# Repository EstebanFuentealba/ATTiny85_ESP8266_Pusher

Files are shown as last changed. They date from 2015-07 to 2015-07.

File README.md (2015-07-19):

# ATTiny85_ESP8266_Pusher
ATTiny85 + ESP8266 + Pusher.com WebSocket Client

Materiales
===================
- ATTiny85
- 2 Led
- Protoboard
- ESP8266
- Arduino UNO
- USBTinyISP (OPCIONAL Para subir código al ATTiny85)
- Cuenta en Pusher.com
- Cables

Instrucciones
===================
## Crear Cuenta en Pusher.com
Pusher es un servicio que provee de servidores websocket para utilizarlo como uno quiera. Esto funciona con tres actores:
- servicio (pusher)
- servidor (envía eventos)
- cliente (se conecta al servicio escucha y recibe eventos)

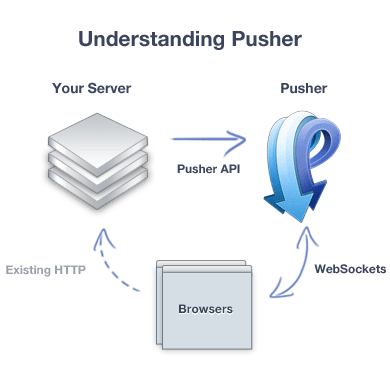
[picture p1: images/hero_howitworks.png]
cómo funciona


De la imagen anterior debemos entender que ATTiny85 funcionará como cliente reemplazando a *Browsers*

Conociendo eso entramos a [https://pusher.com/signup](https://pusher.com/signup) ingresan su email - contraseña o loguearse con alguna cuenta de github o google y confirmar cuenta. Después de eso ya podemos crear apps. Luego de eso los redirecciona a un dashboard y solo deben presionar el botón:

new app

se abre un modal y le damos un nombre y checkeamos *Enable client event* y presionamos *Create App*

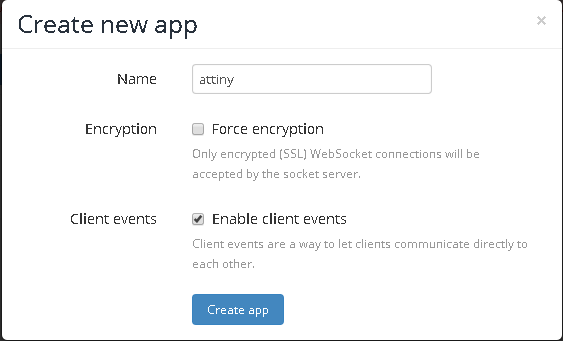
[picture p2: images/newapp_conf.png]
configure new app


ya tenemos una app y podemos comenzar a utilizar el servicio. Nos entrega unos ejemplos de Cliente servidor, pero a nosotros solo nos importará la APP KEY por ejemplo
```
key = '856c493d6d461226XXX'
```

## Actualizar firmware del ESP8266
Lo primero es actualizar el firmware, lo actualizaremos a la versión [AI-v0.9.5.0 AT Firmware.bin](https://github.com/EstebanFuentealba/ATTiny85_ESP8266_Pusher/raw/master/firmware%20esp8266/AI-v0.9.5.0%20AT%20Firmware.bin). Después de probar muchos firmwares es el unico que me funcionó para el ATTiny85 configurado a 4800 bauds.
Primero se sube un sketch vacio al Arduino UNO

```arduino
void setup() {
  // put your setup code here, to run once:
}
void loop() {
  // put your main code here, to run repeatedly:
}
```

Después necesitamos conectar el ESP8266 al Arduino UNO como se ve en el siguiente diagrama

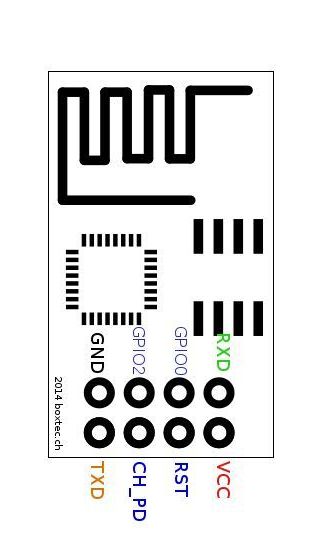
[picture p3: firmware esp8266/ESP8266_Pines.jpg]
ESP8266

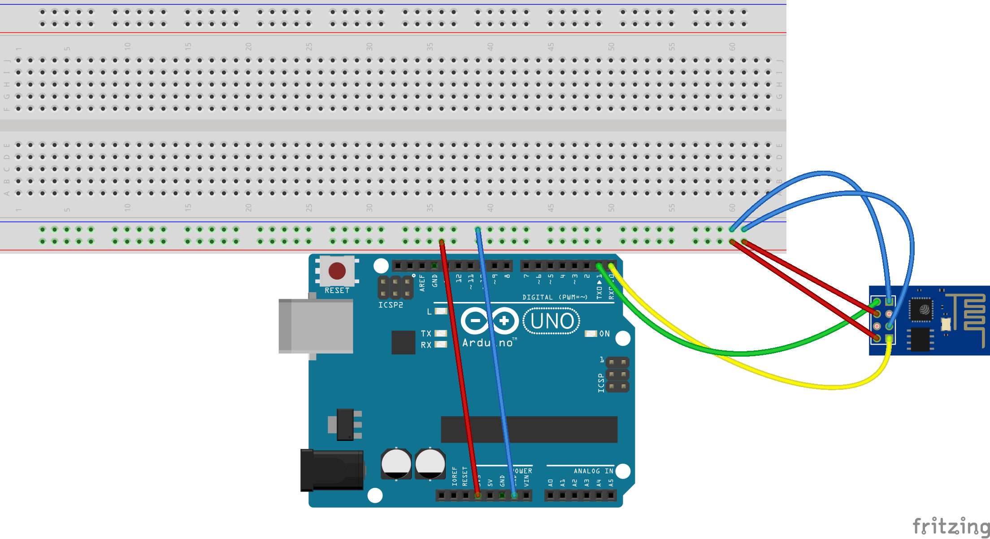
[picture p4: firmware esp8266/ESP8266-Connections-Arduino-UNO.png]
Conexión


Después de conectar utilizaremos el programa [esp8266_flasher.exe](https://github.com/EstebanFuentealba/ATTiny85_ESP8266_Pusher/raw/master/firmware%20esp8266/esp8266_flasher.exe) Para windows o [esptool.py](https://github.com/themadinventor/esptool) para otros sistemas operativos.

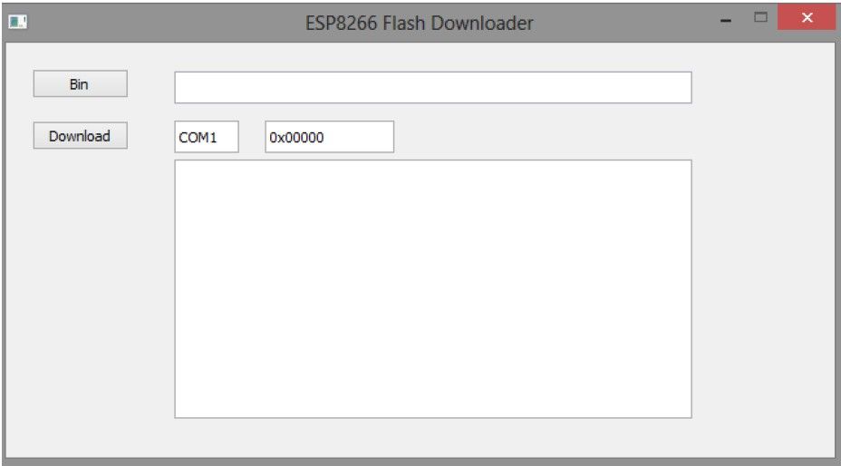
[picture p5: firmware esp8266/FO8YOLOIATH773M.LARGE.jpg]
Programa esp8266_flasher


Se debe seleccionar el archivo presionando el botón "Bin", escribir el puerto donde está conectado el Arduino UNO (COM1) y presionar el botón "Download" , y comenzará a escribirse el firmware en el 8266 imprimiendo algo como lo siguiente

```
connecting ....
Erasing flash...
Writing at 0x00000000... (0 %)
Writing at 0x00000400... (0 %)
Writing at 0x00000800... (0 %)
Writing at 0x0007e800... (99 %)
Writing at 0x0007ec00... (99 %)
Leaving... Failed to leave Flash mode
```

Al terminar de actualizar el firmware deben desconectar del 8266 el pin GPIO0 

## Configurar ESP8266
Despues de tener el nuevo firmware vamos a cambiar un parametro del modulo wifi, debemos dejar el baudaje de comunicación a 4800, por defecto viene con 9600. Para ello nuevamente usaremos Arduino UNO, necesitamos subir el siguiente sketch:

```arduino
#include <SoftwareSerial.h>
SoftwareSerial BT1(3, 2); // RX | TX
void setup() {  
	Serial.begin(9600);
    BT1.begin(9600);
}

void loop() {
	String B= "." ;
	if (BT1.available()) { 
		char c = BT1.read() ;
		Serial.print(c);
	}
	if (Serial.available()){
		char c = Serial.read();
		BT1.print(c);
	}
}
```

y conectaremos el modulo ESP8266 de la siguiente forma:

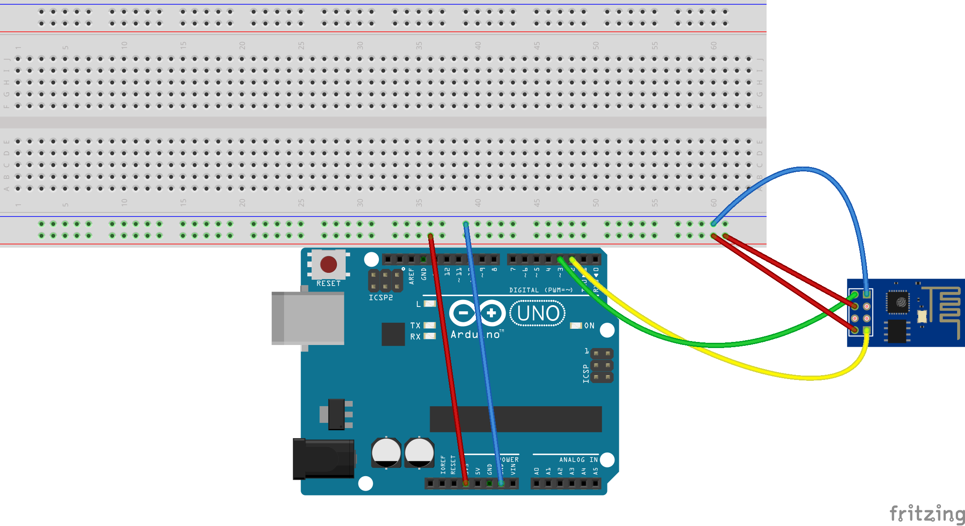
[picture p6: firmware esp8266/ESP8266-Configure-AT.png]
Configurando con comandos AT


Ahora en el programa Arduino vamos a *Herramientas* -> *Monitor Serie* , Seleccionar *Ambos NL & CR* y *9600 baudio*

Configurando Monitor Serie

y podremos ver algo como lo siguiente 

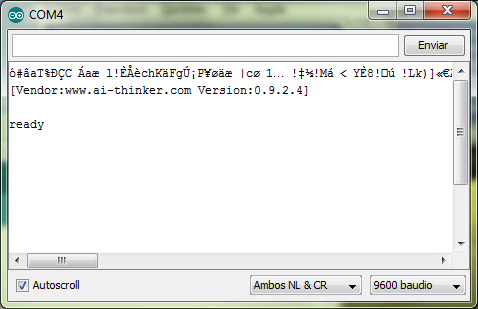
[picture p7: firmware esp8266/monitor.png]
Monitor Serie


Ahora ya podemos comenzar a escribir comandos **AT**, lo primero que podemos escribir es el Comando **AT** que debería responder **OK** 

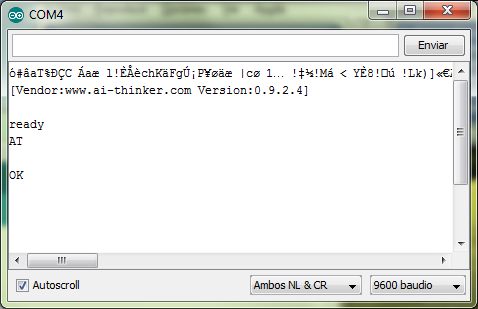
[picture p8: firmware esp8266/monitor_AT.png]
AT


para configurar a 4800 bauds debemos escribir **AT+CIOBAUD=4800** que debería responder **OK** aunque ya no se nos verá el texto porque ahora ya no funciona a 9600 bauds. Para volver a ver texto deben subir nuevamente el sketch anterior pero pasando 4800 al método begin
```arduino
BT1.begin(4800);
```
Ahora ya hemos terminado con la configuración del modulo wifi, aunque si quieren investigar mas [acá dejo un pdf](https://github.com/EstebanFuentealba/ATTiny85_ESP8266_Pusher/raw/master/firmware%20esp8266/ESP8266%20AT%20Command%20Set.pdf) con todos los comandos disponibles que usaremos en los siguientes pasos.

## Subir código al ATTiny85
Para subir el código al integrado Se puede usar Arduino UNO o un ISP yo utilizaré USBTinyISP donde debemos conectar el Attiny85 al ISP de la siguiente forma:

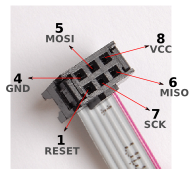
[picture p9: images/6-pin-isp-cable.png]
USBTinyISP
 ATTiny85

Ya conectado debemos agregar ATTiny a las placas del programa Arduino, yo estoy usando la version 1.6.5 que es sencillo, sólo deben ir a *Archivo* -> *Preferencias* donde encontraremos el siguiente campo

Agregar placa

Ahí agregamos éste link que contiene la configuracion del package que contiene las placas ATTiny
```
https://raw.githubusercontent.com/damellis/attiny/ide-1.6.x-boards-manager/package_damellis_attiny_index.json
```
click en OK para guardar la configuración. Ir a *Herramientas* -> *Placa* -> *Boards Manager...* buscar ATtiny y presionar el botón *Install*

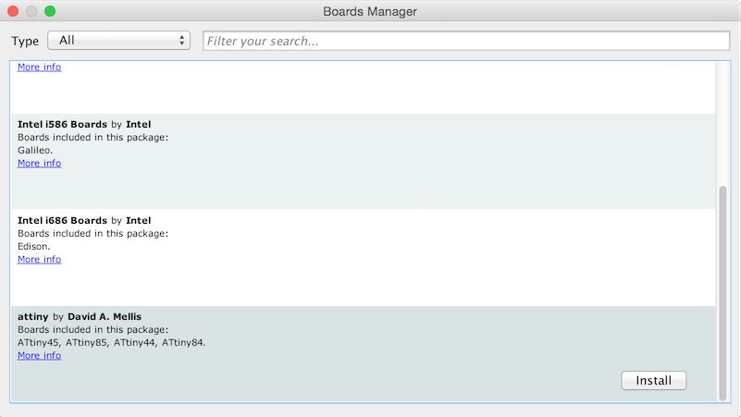
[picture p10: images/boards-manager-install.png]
Install board ATTiny


Ahora ya puedes utilizar ATTiny en Arduino. Ahora configuraremos Arduino Anda a *Herramientas* 
- **Placa** y selecciona *ATtiny*
- **Procesador** ATTiny85
- **Clock** 8 MHz (internal)
- **Programador** USBtinyISP

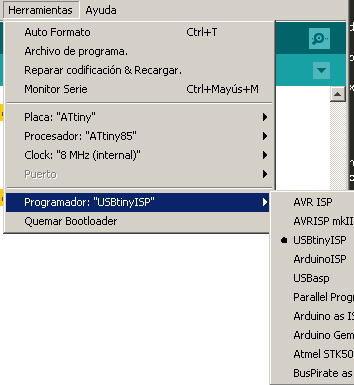
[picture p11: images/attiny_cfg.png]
board ATTiny


Importante es Presionar **Quemar Bootloader**, cuando no hice eso el programa andaba lento

Ahora solo deben configurar [ATTiny85WebSocketClient.ino](https://github.com/EstebanFuentealba/ATTiny85_ESP8266_Pusher/blob/master/attiny85/ATTiny85WebSocketClient.ino) agregando la información de su red wifi y la Key de pusher que obtuvimos en el Paso 1

```arduino
#define SSID        "WifiAP"
#define PASS        "password"
#define PUSHER_KEY  "xxxxxxxxxxxxxxx"
```
El codigo se conecta como Cliente a Pusher esperando eventos en el channel **test_channel**, los eventos que definí son los siguientes:

- **ledAOn** 
- **ledAOff**
- **ledBOn**
- **ledBOff**

esos eventos prenderán o apagarán 2 leds. A continuación dejo el diagrama de como deben ir conectadas las leds y el módulo ESP8266 al ATTiny85

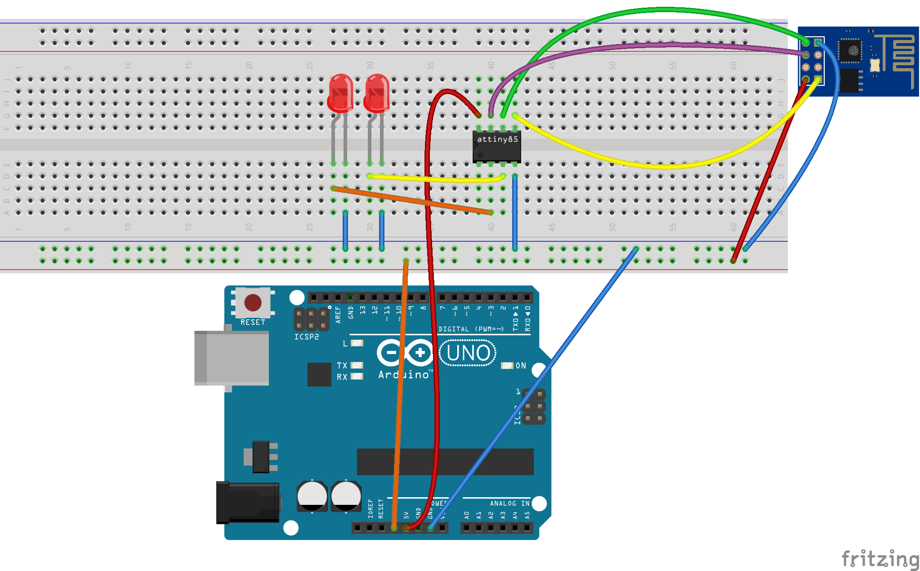
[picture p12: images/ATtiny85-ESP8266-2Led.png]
cableado


Ahora solo debemos subir el código al ATTint85 y esperar que conecte.

## Testeando programa
Aqui dejo un video con el programa y la configuración corriendo

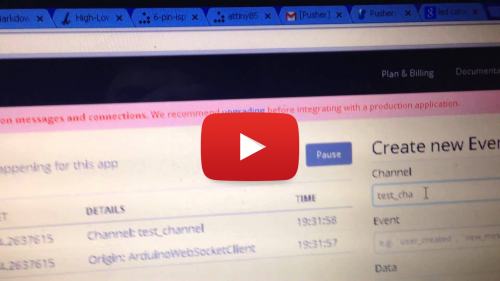
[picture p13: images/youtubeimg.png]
Video (http://youtu.be/ycAC6Tfkjng)


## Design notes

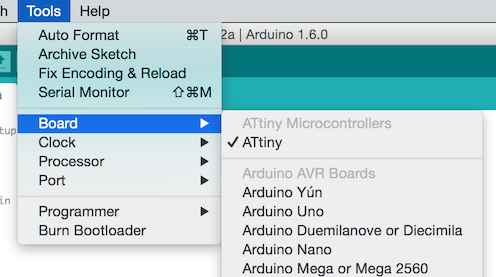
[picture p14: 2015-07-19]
images/ATtiny-Arduino-1.6.png

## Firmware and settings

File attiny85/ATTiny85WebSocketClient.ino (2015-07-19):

#include <SoftwareSerial.h>
/*
*   efuentealba@json.cl
*/
//CONFIGURE
#define SSID        "WifiAP"
#define PASS        "password"
#define PUSHER_KEY  "xxxxxxxxxxxxxxx"


#define SOFT_RX_PIN     1
#define SOFT_TX_PIN     0
#define ESP_ENABLE_PIN  2
#define LED_A 4
#define LED_B 3
#define TIMEOUT     5000
#define CONTINUE    false
#define HALT        true

char str_buffer[64];

const char STR_OK[] PROGMEM         = "OK";
const char WS_OK[] PROGMEM          = "HTTP/1.1 101";
const char WS_PING[] PROGMEM        = "pusher:ping";
const char STR_READY[] PROGMEM      = "ready";
const char STR_SENDMODE[] PROGMEM   = ">";
const char STR_APNAME[] PROGMEM     = "+CWJAP:\"";
const char SUBSCRIBE_JSON[] PROGMEM = "{\"event\":\"pusher:subscribe\",\"data\":{\"channel\":\"test_channel\"}}";
const char PONG_JSON[] PROGMEM      = "{\"event\":\"pusher:pong\",\"data\":{}}";
const char ping[] PROGMEM           = "ping";

/*
*   EVENTOS PUSHER.COM
*/
const char ledAOn[] PROGMEM         = "ledAOn";
const char ledAOff[] PROGMEM        = "ledAOff";
const char ledBOn[] PROGMEM         = "ledBOn";
const char ledBOff[] PROGMEM        = "ledBOff";

bool connected = false;


byte ledAonC   = 0;
byte ledAoffC  = 0;
byte ledBonC   = 0;
byte ledBoffC  = 0;
byte pingC     = 0;


SoftwareSerial SoftSerial(SOFT_RX_PIN, SOFT_TX_PIN); // RX, TX

void setup() {
  pinMode(SOFT_TX_PIN, OUTPUT);
  pinMode(LED_A, OUTPUT);
  pinMode(ESP_ENABLE_PIN, OUTPUT);
  pinMode(LED_B, OUTPUT);
  digitalWrite(SOFT_TX_PIN, LOW);
  digitalWrite(LED_A, LOW);
  digitalWrite(LED_B, LOW);
  digitalWrite(ESP_ENABLE_PIN, LOW);
  SoftSerial.begin(4800);
  //SoftSerial.setTimeout(TIMEOUT);
  delay(300);
  digitalWrite(ESP_ENABLE_PIN, HIGH);
  SoftSerial.println(F("AT+RST"));
  SoftSerial.flush();
  if (!waitForString(getString(STR_READY), 5, 2000)) {
    return;
  }
  digitalWrite(LED_A, HIGH);
  delay(500);
  digitalWrite(LED_A, LOW);
  SoftSerial.println(F("ATE0"));
  SoftSerial.flush();
  if (waitForString(getString(STR_OK), 2, 2000)) {
    digitalWrite(LED_A, HIGH);
    delay(500);
    digitalWrite(LED_A, LOW);
    boolean connection_established = false;
    for (int i = 0; i < 5; i++) {
      if (connectWiFi()) {
        connection_established = true;
        break;
      }
    }
    if (!connection_established) {
      return;
    }
    SoftSerial.println(F("AT+CIPMODE=1"));
    SoftSerial.flush();
    if (!waitForString(getString(STR_OK), 2, 1000)) {
      return;
    }
    SoftSerial.println(F("AT+CIPMUX=0"));
    SoftSerial.flush();
    if (!waitForString(getString(STR_OK), 2, 1000)) {
      return;
    }
  } else {
    //digitalWrite(LED_B, HIGH);
  }
}

void wssend(char *data) {
  SoftSerial.print((char)0);
  SoftSerial.print(data);
  SoftSerial.print((char)255);
  SoftSerial.flush();
}
void loop() {
  if (!connected) {
    SoftSerial.println("AT+CIPSTART=\"TCP\",\"ws.pusherapp.com\",80");
    SoftSerial.flush();
    if (!waitForString(getString(STR_OK), 2, 1000)) {
      return;
    }

    SoftSerial.println(F("AT+CIPSEND"));
    SoftSerial.flush();
    if (waitForString(getString(STR_SENDMODE), 1, 1000)) {

      SoftSerial.print("GET /app/");
      SoftSerial.print(PUSHER_KEY);
      SoftSerial.print("?client=js&version=2.2&protocol=5");
      SoftSerial.print("HTTP/1.1\r\n");
      SoftSerial.print("Upgrade: WebSocket\r\n");
      SoftSerial.print("Connection: Upgrade\r\n");
      SoftSerial.print("Host: ws.pusherapp.com\r\n");
      SoftSerial.print("Origin: ArduinoWebSocketClient\r\n");
      SoftSerial.print("\r\n");
      SoftSerial.flush();
      if (waitForString(getString(WS_OK), 2, 1000)) {

        wssend(getString(SUBSCRIBE_JSON));
        connected = true;

      } else {
        //Serial.println("ERROR http");
      }

    } else {
      SoftSerial.println(F("AT+CIPCLOSE"));
      SoftSerial.flush();
    }
  }

  if (connected) {
    if (SoftSerial.available()) {
      char ch = SoftSerial.read();
      if (ch == getString(ledAOff)[ledAoffC]) {
        if (++ledAoffC == 7) {
          digitalWrite(LED_A, LOW);
        }
      } else {
        ledAoffC = 0;
      }
      if (ch == getString(ledAOn)[ledAonC]) {
        if (++ledAonC == 6) {
          digitalWrite(LED_A, HIGH);
        }
      } else {
        ledAonC = 0;
      }
      if (ch == getString(ledBOff)[ledBoffC]) {
        if (++ledBoffC == 7) {
          digitalWrite(LED_B, LOW);
        }
      } else {
        ledBoffC = 0;
      }
      if (ch == getString(ledBOn)[ledBonC]) {
        if (++ledBonC == 6) {
          digitalWrite(LED_B, HIGH);
        }
      } else {
        ledBonC = 0;
      }
      if (ch == getString(ping)[pingC]) {
        if (++pingC == 4) {
          wssend(getString(PONG_JSON));
        }
      } else {
        pingC = 0;
      }
    }
  }
}

boolean connectWiFi() {
  SoftSerial.println(F("AT+CWJAP?"));
  SoftSerial.flush();
  if (waitForString(getString(STR_APNAME), 8, 500)) {
    return true;
  }
  SoftSerial.println(F("AT+CWMODE=1"));
  SoftSerial.flush();
  waitForString(getString(STR_OK), 2, 500);

  SoftSerial.print("AT+CWJAP=\"");
  SoftSerial.print(SSID);
  SoftSerial.print("\",\"");
  SoftSerial.print(PASS);
  SoftSerial.println("\"");
  SoftSerial.flush();
  if (waitForString(getString(STR_OK), 2, 10000)) {
    return true;
  } else {
    return false;
  }
}

bool waitForString(char* input, uint8_t length, unsigned int timeout) {

  unsigned long end_time = millis() + timeout;
  int current_byte = 0;
  uint8_t index = 0;

  while (end_time >= millis()) {

    if (SoftSerial.available()) {
      current_byte = SoftSerial.read();
      if (current_byte != -1) {
        if (current_byte == input[index]) {
          index++;
          if (index == length) {
            return true;
          }
        } else {
          index = 0;
        }
      }
    }
  }
  return false;
}
char* getString(const char* str) {
  strcpy_P(str_buffer, (char*)str);
  return str_buffer;
}

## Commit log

2015-07-19 cableado ATtiny85 ESP8266 2 Led
2015-07-19 codigo y cableado
2015-07-19 diagrama leds
